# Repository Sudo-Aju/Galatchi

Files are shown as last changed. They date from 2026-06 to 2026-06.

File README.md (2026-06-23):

<div align="center">

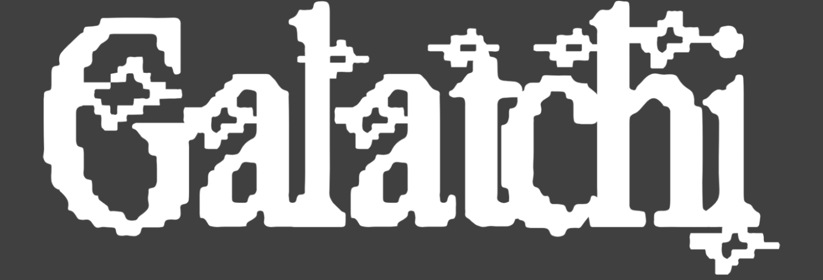
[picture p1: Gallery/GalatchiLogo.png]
galatchilogo
#  galatchilogo <br><br> 

A Tamagotchi but from another planet    

<p>



</p>

### _Your care determines the alien you get._

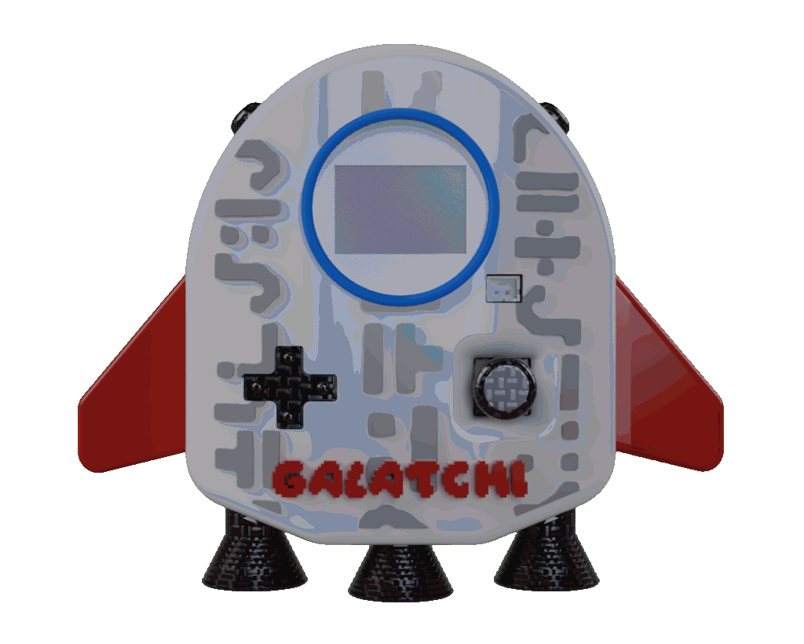
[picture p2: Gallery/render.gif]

</div>

---

# Zine

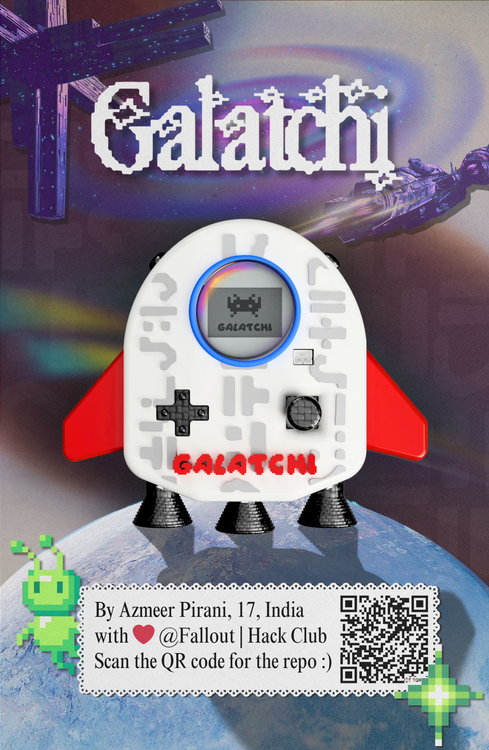
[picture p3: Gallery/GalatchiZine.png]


---

# Gallery

<div align="center">

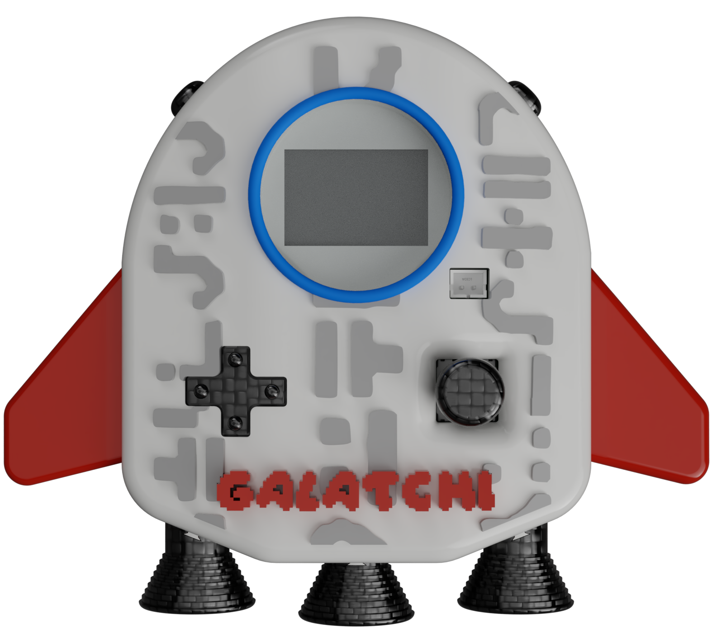
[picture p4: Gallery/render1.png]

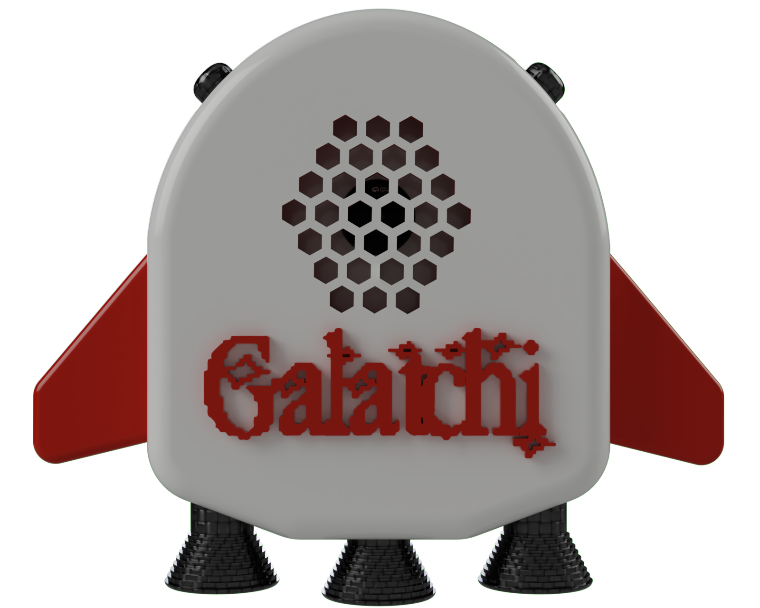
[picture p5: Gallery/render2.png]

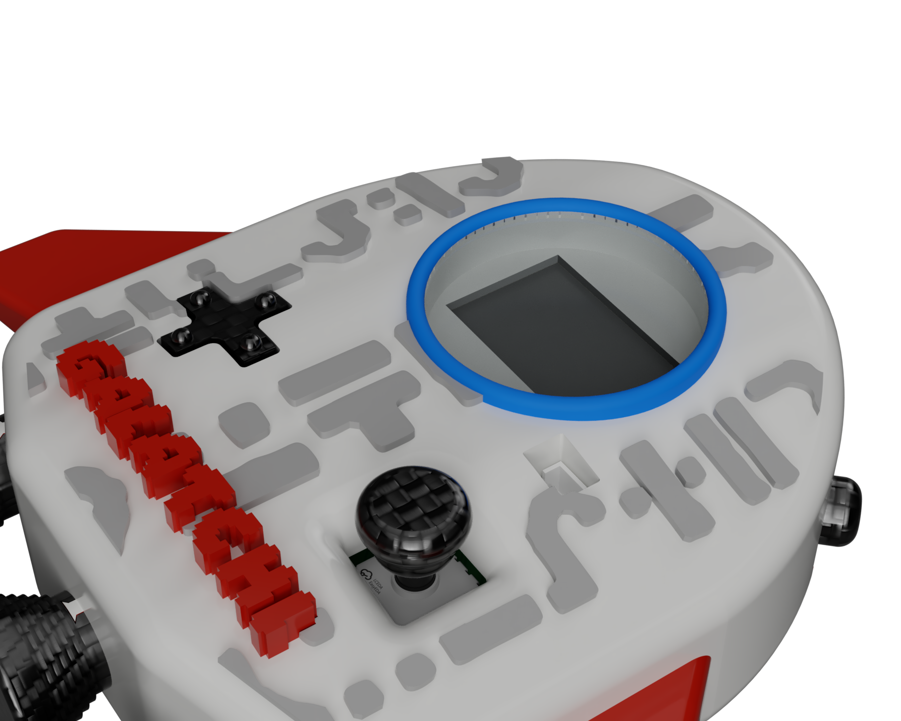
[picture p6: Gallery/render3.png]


</div>

---

# Motivation

The Tamagotchi is a classis retro game played by not only kids but all ages time to time. 

Galatchi is trying to be something similar but instead of:

### _Your care determines the **PET** you get._

its

### _Your care determines the **ALIEN** you get._

The goal was simple:

> To make something nostalgic enough but so unique and related to an area no one ever though of.

---

# Features 

- XIAO ESP32-C3 Plateform
- 128x64 I2C OLED Display
- LSM6DSOXTR 6-Axis IMU
- PCA9535 GPIO Expander
- 5-Way Naavigation Joystick
- Dual Action Side Buttons ( like the ones in ps5 controller 🤓)
- Pizo Buzzer Audio
- LiPo Battery Powered
- USB-C Programming
- Open Source

---

# Gameplay

The exact gameplay is still under development, but some basic interaction are built and all peripherals are working. The OLED display provied animatino and status information, while the joystick and buttons are used for navigations and actions. The IMU enables motion-based interactions such as shaking titling and gesture detection. Audio feedback is provieded though the integrated buzzer.

Beyond this basic gameplay, I have planned to make it in such a way where a extraterestial creature's egg is found in the spaceship, and u have to control the spaceshpi with help of the IMU sensors, and other inputs.

---

# Hardware Stack

|Parameter|Value|
|---|---|
|MCU|Seeed XIAO ESP32-C3|
|Display |OLED Display|
|Motion Sensor|6-Axis IMU|
|Audio|Piezo Buzzer|
|Controls|5-Way Joystick + 4 Button Dpad|
|Battery|Rechargeable LiPo|
|Expansion|I/O Expander|
|Connectivity|UCB-C|
|PCB|Custom 2-Layer PCB|
|Firmware|Open Source|

---

# BOM

|No.|Quantity|Comment |Designator |Footprint |Value |Manufacturer Part|Manufacturer|Supplier Part|Supplier|LCSC Price |Link |
|---|---|---|---|---|---|---|---|---|---|---|---|
|1  |1 |4kHz |BUZZER1 |BUZ-TH_BD12.5-P6.50-D1.4 |4kHz |1207-P6.5MM |XHXDZ(兴华鑫)  |C49246964 |LCSC | |https://www.lcsc.com/product-detail/C49246964.html|
|2  |1 |B2B-PH-K-S-GW|CN1 |CONN-TH_B2B-PH-K-S | |B2B-PH-K-S-GW |JST |C5251182 |LCSC | |https://www.lcsc.com/product-detail/C5251182.html |
|3  |2 |TL1100CF160Q |KEY1 KEY2 |KEY-TH_TL1100CF160Q | |TL1100CF160Q |E-Switch |C273459 |LCSC | |https://www.lcsc.com/product-detail/C273459.html  |
|4  |1 |2.2K |R1 |R0603 |2.2K | | | | |12.0978 | |
|5  |1 |Joystick |SW1 |SW-SMD-6P-L10.5-W10.0_C2858290 | |Joystick |SHOU HAN(首韩)|C2858290 |LCSC | |https://www.lcsc.com/product-detail/C2858290.html |
|6  |4 |F1B060211S |SW2 SW3 SW4 SW5|SW-TH_4P-L4.5-W4.5-P3.00-LS4.8 | |F1B060211S |SAMZO(三佐) |C29780794 |LCSC | |https://www.lcsc.com/product-detail/C29780794.html|
|7  |1 |XIAO-ESP32-C3|U1 |Seeed_Studio_XIAO_Series:XIAO-ESP32-C3-SMD|XIAO-ESP32-C3-SMD| | | | |12.0978|https://www.seeedstudio.com/XIAO-ESP32C3-p-5431.html |
|8  |1 |HS96L03W2C03 |U2 |OLED-TH_L27.8-W27.2-P2.54_C9900033791 | |HS96L03W2C03 |HS(汉昇) |C5248080 |LCSC | |https://www.lcsc.com/product-detail/C5248080.html |
|9  |1 |PCA9535PW |U3 |TSSOP-24_L7.8-W4.4-P0.65-LS6.4-BL | |PCA9535PW |NXP(恩智浦) |C129517 |LCSC | |https://www.lcsc.com/product-detail/C129517.html  |
|10 |1 |LSM6DSOXTR |U4 |LGA-14L_L3.0-W2.5-P0.50-TL | |LSM6DSOXTR |ST(意法半导体) |C481766 |LCSC | |https://www.lcsc.com/product-detail/C481766.html  |

---

# PCB Design

The board includes:
Seed XIAO ESP32-C3
OLED Display Interface
PCA9535 I/O Expander
LSM6DSOXTR 6-Axis IMU
Piezo Audio System
Battery Connector
UCB-C Programming Interface

---

# PCB

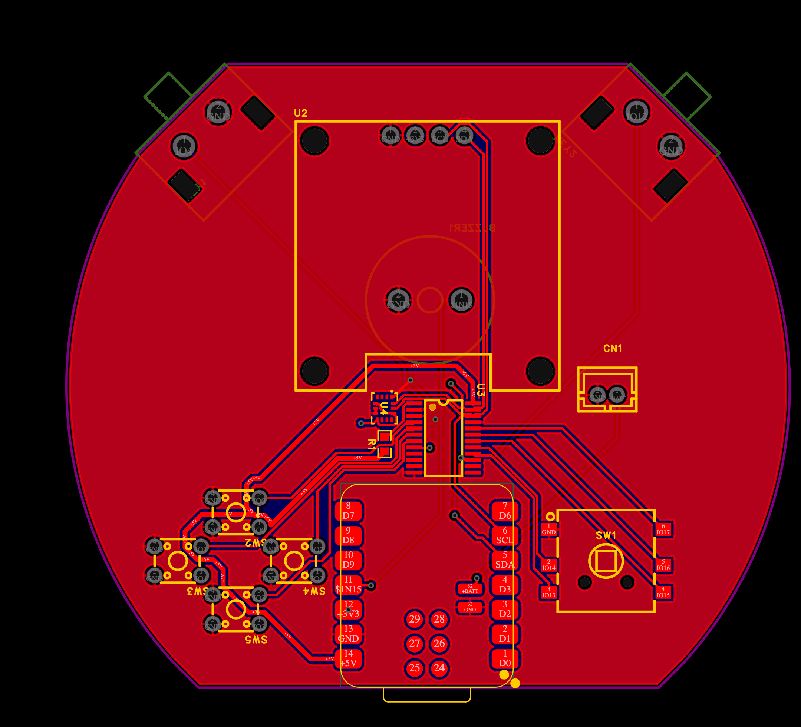
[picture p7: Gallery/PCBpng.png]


---

# Schematic

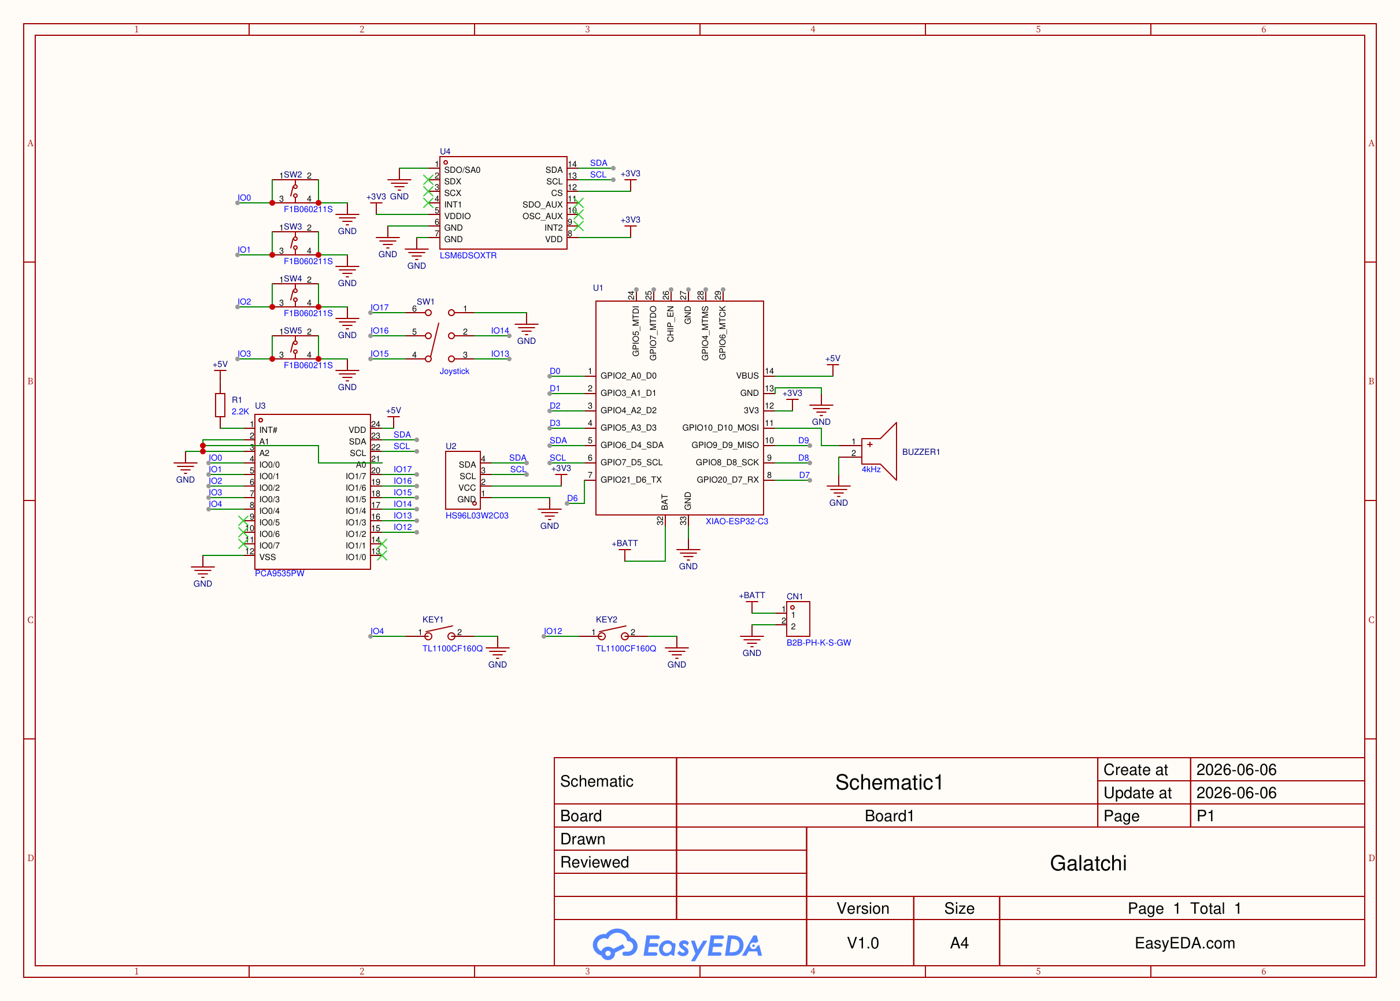
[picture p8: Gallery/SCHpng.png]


---

# Build Guide

## 1. Order the  PCB
```bash
./PCB/GalatchiGerber.zip
```

## 2. Order Components

```bash
./PCB/GalatchiBOM.csv
```

## 3. Assemble the Hardware

Recommended tools:

- Flux
- Fine-tip Soldering Iron
- Tweezers
- Hot Air Station

## 4. Flash the Firmware

Connect the device using USB-C.

```bash
./Firmware/
```

## 5. Hatch Your Alien

Power on Galatchi.

Watch your egg hatch.

Begin exploring an entirely unknown spcies.

---

# Applications

Retro Gaming Enthusiasts
Open Source Harware Projects
STEM Education
Embedded Systems Learning
Interactive Electronics

---

# Repository Structure

```bash
Galatchi/
├── PCB/
├── CAD/
├── Firmware/
├── Assets/
├── Gallery/
├── Docs/
└──README.md
```

---

# Current Status

- [X] Concept Design
- [X] Schematic Design
- [X] PCB Design
- [ ] Final Build
- [ ] Community Testing

---

# Contributing

Contributions, suggestions, and feedback are welcome.

If you'd like to improve Galatchi

```bash
git clone 
cd Galatchi
```

1. Create a feature  branch
2. Make your changes
3. Commit your work
4. Open a pull request

---

# Creator

### Azmeer Pirani

Built with ❤️ for:
- Tiny Gadgets
- Alien Worlds
- Retro Electronics
- Open Source Hardware
- Pocket-Sized Adventures

---

# License

This project is licensed under the MIT License.

---

<div align="center">

# GALATCHI

### _Your care determines the alien you get._

</div>

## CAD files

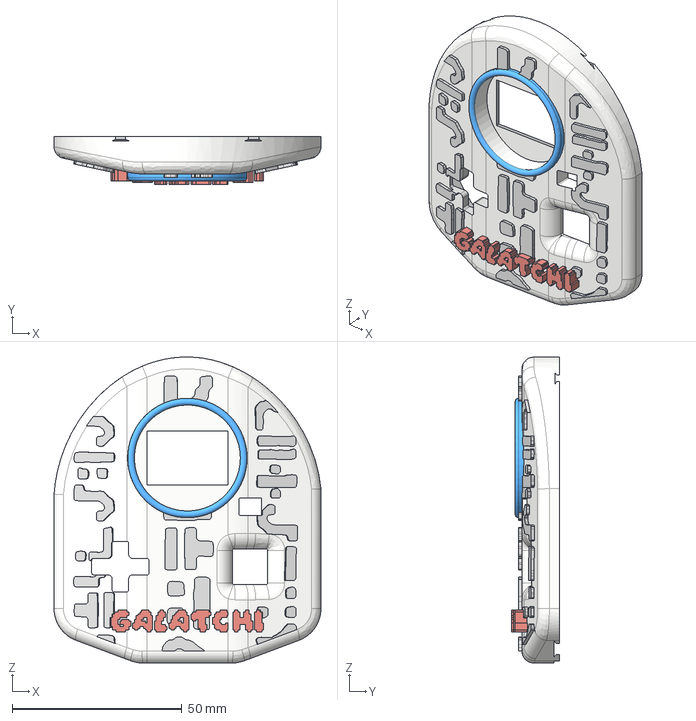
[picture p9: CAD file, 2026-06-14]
CAD/STEP/UpperPart.step
78.7 x 14.0 x 90.2 mm

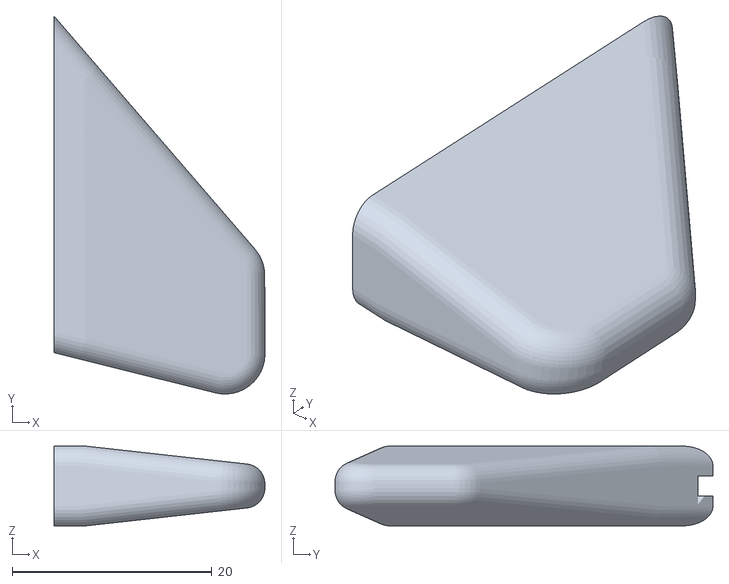
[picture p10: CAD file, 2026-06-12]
CAD/STL/WingR.stl
21.1 x 37.8 x 8.00

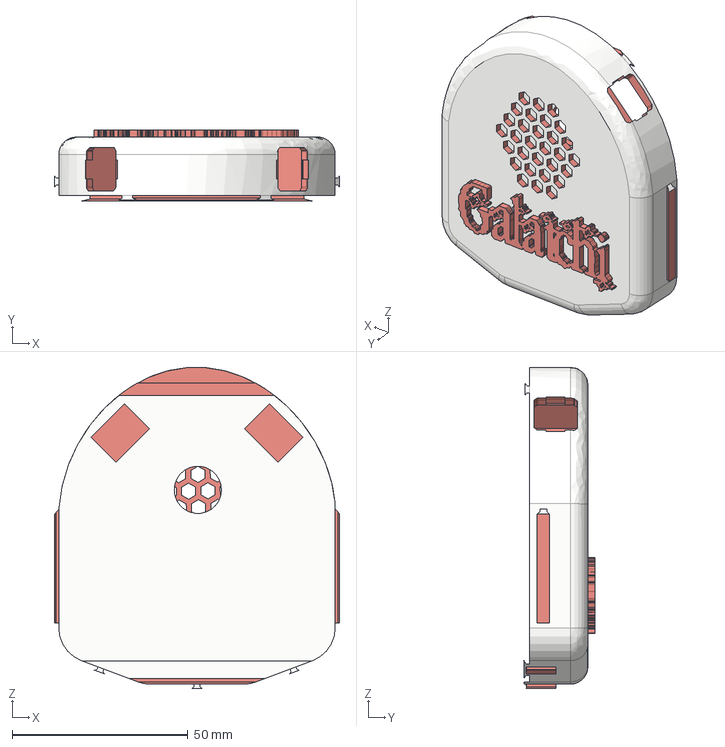
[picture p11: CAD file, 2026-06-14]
CAD/STEP/BottomPart.step
81.2 x 20.2 x 91.3 mm

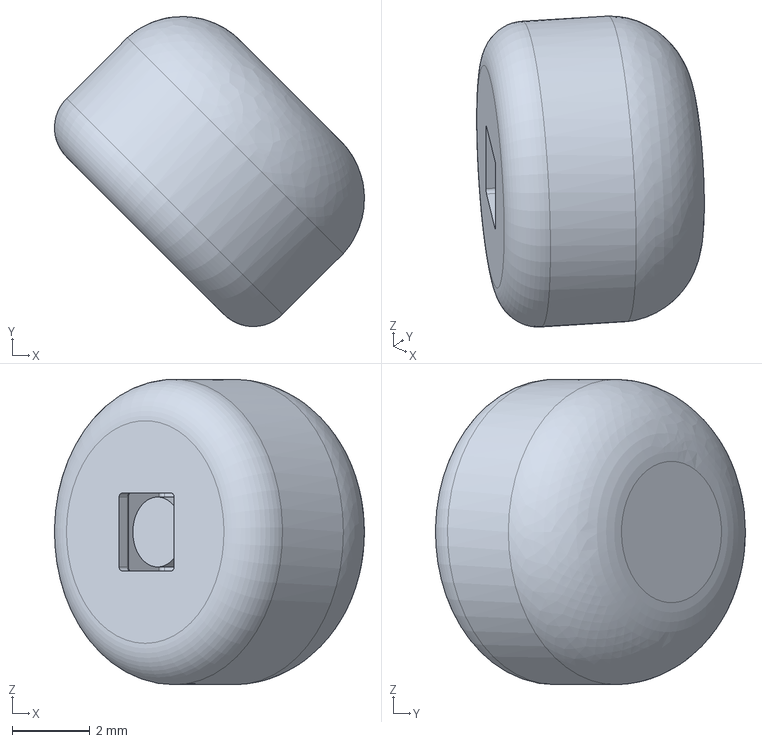
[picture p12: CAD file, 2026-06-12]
CAD/STEP/SideButtonR.step
7.98 x 7.98 x 7.86 mm

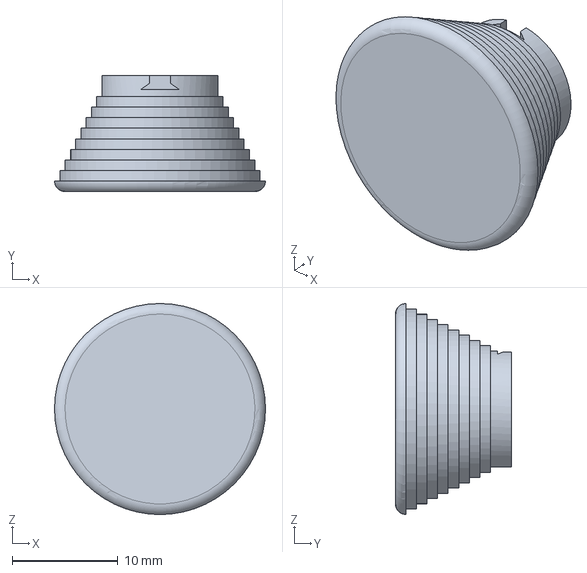
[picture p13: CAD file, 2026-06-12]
CAD/STEP/NozzleC.step
20.0 x 11.0 x 20.0 mm

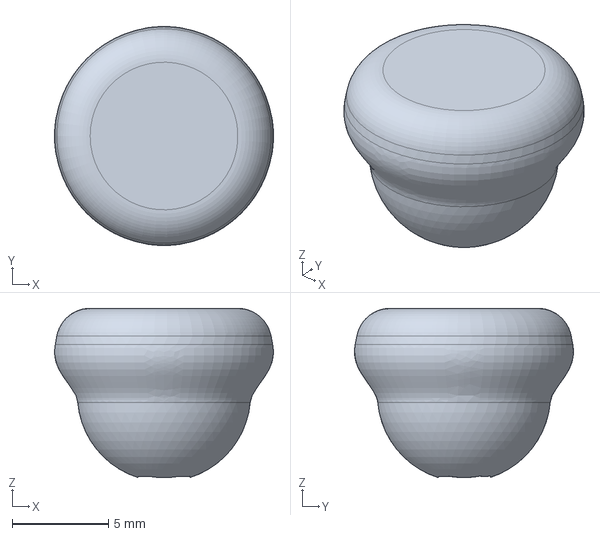
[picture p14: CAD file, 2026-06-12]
CAD/STEP/Joystick.step
11.4 x 11.4 x 8.80 mm

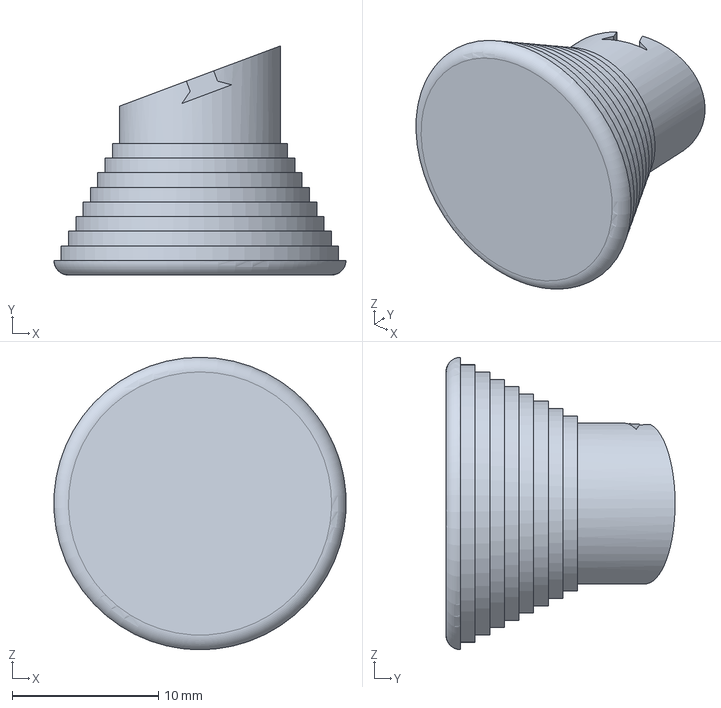
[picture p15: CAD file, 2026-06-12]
CAD/STEP/NozzleR.step
20.0 x 15.7 x 20.0 mm

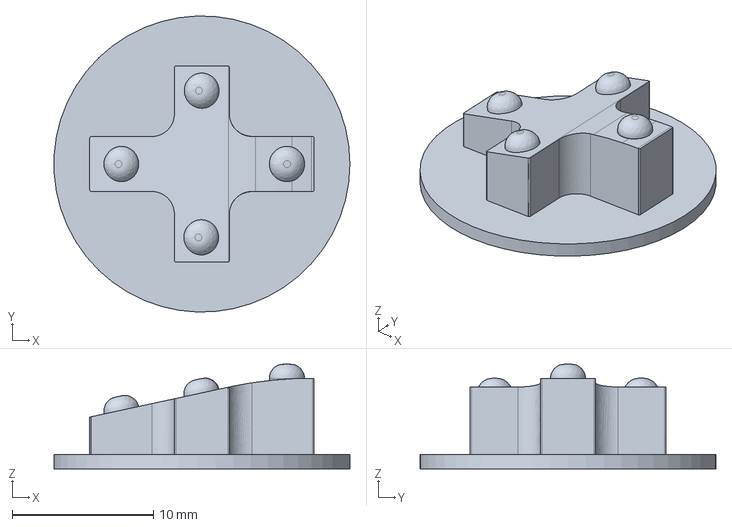
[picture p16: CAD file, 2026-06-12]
CAD/STEP/Dpad.step
21.0 x 21.0 x 7.42 mm

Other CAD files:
CAD/STEP/WingL.step
CAD/STEP/WindR.step
CAD/STEP/SideButtonL.step
CAD/STEP/NozzleL.step
CAD/STL/BottomPart.stl
CAD/STL/Dpad.stl
CAD/STL/Joystick.stl
CAD/STL/NozzleC.stl
CAD/STL/NozzleL.stl
CAD/STL/NozzleR.stl
CAD/STL/SideButtonL.stl
CAD/STL/SideButtonR.stl
CAD/STL/UpperPart.stl
CAD/STL/WingL.stl

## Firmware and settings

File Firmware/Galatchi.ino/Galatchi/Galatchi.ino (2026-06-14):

#include <Wire.h>
#include <Adafruit_GFX.h>
#include <Adafruit_SSD1306.h>
#include <PCA95x5.h>
#include <Adafruit_LSM6DSOX.h>
#include <Adafruit_Sensor.h>
#include <SPI.h>

#define I2C_SDA         5
#define I2C_SCL         6
#define OLED_ADDR       0x3C
#define PCA9535_ADDR    0x20
#define BUZZER_PIN      10
#define JOY_DOWN        11
#define JOY_RIGHT       12
#define JOY_PRESS       13
#define JOY_UP          14
#define JOY_LEFT        15
#define BTN_RIGHT_90    10 //key 2
#define BTN_LEFT_90     4  // key 1
#define BTN_UP          0
#define BTN_DOWN        3
#define BTN_LEFT        1
#define BTN_RIGHT       2

PCA9555 ioex;
Adafruit_LSM6DSOX imu;

#define SCREEN_WIDTH 128
#define SCREEN_HEIGHT 64
#define OLED_RESET -1

Adafruit_SSD1306 display(SCREEN_WIDTH, SCREEN_HEIGHT, &Wire, OLED_RESET);

struct Alien {
  int hunger;
  int happiness;
  int energy;
  unsigned long age;
};

Alien alien;
int selectedMenu = 0;
const int MENU_COUNT = 3;

enum Screen {
  SCREEN_MAIN,
  SCREEN_FEED,
  SCREEN_PLAY,
  SCREEN_SLEEP
};

Screen currentScreen = SCREEN_MAIN;

bool pcaPressed(uint8_t pin) {
    uint16_t state = ioex.read();
    return !(state & (1 << pin));
}

const unsigned char PROGMEM alienSleep[] = {
  0b00000000, 0b00000000,
  0b00000000, 0b00000000,
  0b00000000, 0b00000000,
  0b00011000, 0b00011000,
  0b00011111, 0b11111000,
  0b00000111, 0b11100000,
  0b00001111, 0b11110000,
  0b00001101, 0b10110000,
  0b00111111, 0b11111100,
  0b00111111, 0b11111100,
  0b00111111, 0b11111100,
  0b00111111, 0b11111100,
  0b00001111, 0b11110000,
  0b00001111, 0b11110000,
  0b00001100, 0b00110000,
  0b00001100, 0b00110000
};

const unsigned char PROGMEM alienSad[] = {
  0b00000000, 0b00000000,
  0b00000000, 0b00000000,
  0b00011000, 0b00011000,
  0b00011000, 0b00011000,
  0b00000111, 0b11100000,
  0b00000111, 0b11100000,
  0b11001101, 0b10110011,
  0b11001101, 0b10110011,
  0b00111111, 0b11111100,
  0b00111110, 0b01111100,
  0b00001101, 0b10110000,
  0b00001111, 0b11110000,
  0b00001111, 0b11110000,
  0b00001111, 0b11110000,
  0b00001100, 0b00110000,
  0b00001100, 0b00110000
};

const unsigned char PROGMEM alienHappy[] = {
  0b00000000, 0b00000000,
  0b00000000, 0b00000000,
  0b00011000, 0b00011000,
  0b00011000, 0b00011000,
  0b00000111, 0b11100000,
  0b00000111, 0b11100000,
  0b11001101, 0b10110011,
  0b11001101, 0b10110011,
  0b00111111, 0b11111100,
  0b00111101, 0b10111100,
  0b00001110, 0b01110000,
  0b00001111, 0b11110000,
  0b00001111, 0b11110000,
  0b00001111, 0b11110000,
  0b00001100, 0b00110000,
  0b00001100, 0b00110000
};

const unsigned char PROGMEM alienNeutral[] = {
  0b00000000, 0b00000000,
  0b00011111, 0b11111000,
  0b00100000, 0b00000100,
  0b01000000, 0b00000010,
  0b01001111, 0b01110010,
  0b01000000, 0b00000010,
  0b01000000, 0b00000010,
  0b01000000, 0b00000010,
  0b01000011, 0b11000010,
  0b01000000, 0b00000010,
  0b01000000, 0b00000010,
  0b00100000, 0b00000100,
  0b00011111, 0b11111000,
  0b00000000, 0b00000000,
  0b00000000, 0b00000000,
  0b00000000, 0b00000000
};

void setup() {
  Serial.begin(115200);
  Wire.begin(I2C_SDA, I2C_SCL);

  
  pinMode(BUZZER_PIN, OUTPUT);

  
  ioex.attach(Wire);
  ioex.direction(PCA95x5::Direction::IN_ALL);
  ioex.polarity(PCA95x5::Polarity::ORIGINAL_ALL);

  
  if(!display.begin(SSD1306_SWITCHCAPVCC, OLED_ADDR)) {
    Serial.println("OLED Init Failed!");
  } else {
    display.clearDisplay();
    display.setTextSize(1);
    display.setTextColor(SSD1306_WHITE);
    display.setCursor(0, 0);
    display.println("Galagotchi Init..");
    display.display();
  }

  
  if (!imu.begin_I2C()) {
    Serial.println("Failed to find LSM6DSOX chip");
  } else {
    Serial.println("LSM6DSOX Found!");
    
    imu.setAccelRange(LSM6DS_ACCEL_RANGE_4_G);
    imu.setGyroRange(LSM6DS_GYRO_RANGE_500_DPS);
    imu.setAccelDataRate(LSM6DS_RATE_104_HZ);
    imu.setGyroDataRate(LSM6DS_RATE_104_HZ);
  }

  delay(1000);
  
  alien.hunger = 80;
  alien.happiness = 80;
  alien.energy = 80;
  alien.age = 0;
}

unsigned long lastUpdate = 0;
unsigned long lastButtonPress = 0;
unsigned long lastShakeTime = 0;

void updateAlien() {
  if (millis() - lastUpdate > 5000) {
    alien.hunger--;
    alien.happiness--;
    alien.energy--;

    if (alien.hunger < 0) alien.hunger = 0;
    if (alien.happiness < 0) alien.happiness = 0;
    if (alien.energy < 0) alien.energy = 0;

    alien.age += 5;
    lastUpdate = millis();
  }
}

void checkIMU() {
  
  if (millis() - lastShakeTime < 1000) return;

  sensors_event_t accel;
  sensors_event_t gyro;
  sensors_event_t temp;
  imu.getEvent(&accel, &gyro, &temp);

  
  float magnitude = sqrt(pow(accel.acceleration.x, 2) + 
                         pow(accel.acceleration.y, 2) + 
                         pow(accel.acceleration.z, 2));

  
  if (magnitude > 25.0) {
    alien.happiness += 15;
    alien.energy -= 5;
    
    if(alien.happiness > 100) alien.happiness = 100;
    if(alien.energy < 0) alien.energy = 0;

    // Shake sound effect
    tone(BUZZER_PIN, 1200, 100);
    delay(100);
    tone(BUZZER_PIN, 1600, 150);
    
    lastShakeTime = millis();
  }
}

void checkButtons() {
  if (millis() - lastButtonPress < 200) return;

  if (pcaPressed(JOY_LEFT)) {
    currentScreen = SCREEN_FEED;
    tone(BUZZER_PIN, 1000, 50);
    lastButtonPress = millis();

  } else if (pcaPressed(JOY_UP)) {
    currentScreen = SCREEN_PLAY;
    tone(BUZZER_PIN, 1200, 50);
    lastButtonPress = millis();

  } else if (pcaPressed(JOY_RIGHT)) {
    currentScreen = SCREEN_SLEEP;
    tone(BUZZER_PIN, 800, 50);
    lastButtonPress = millis();

  } else if (pcaPressed(JOY_PRESS)) {
    currentScreen = SCREEN_MAIN;
    tone(BUZZER_PIN, 1500, 50);
    lastButtonPress = millis();

  } else if (pcaPressed(BTN_LEFT_90)) {
    alien.hunger += 5;
    if(alien.hunger > 100) alien.hunger = 100;
    tone(BUZZER_PIN, 1800, 80);
    lastButtonPress = millis();

  } else if (pcaPressed(BTN_RIGHT_90)) {
    alien.happiness += 5;
    if(alien.happiness > 100) alien.happiness =100;
    tone(BUZZER_PIN, 2200, 40);
    delay(50);
    tone(BUZZER_PIN, 2200, 60);
    lastButtonPress = millis();

  } else if (pcaPressed(BTN_UP)) {
    alien.energy += 5;
    if (alien.energy > 100) alien.energy = 100;
    tone(BUZZER_PIN, 1600, 50);
    lastButtonPress = millis();

  } else if (pcaPressed(BTN_DOWN)) {
    alien.energy -= 5;
    if (alien.energy < 0) alien.energy = 0;
    tone(BUZZER_PIN, 600, 50);
    lastButtonPress = millis();

  } else if (pcaPressed(BTN_LEFT)) {
    selectedMenu--;
    if (selectedMenu < 0) selectedMenu = MENU_COUNT - 1;
    tone(BUZZER_PIN, 1000, 30);
    lastButtonPress = millis();

  } else if (pcaPressed(BTN_RIGHT)) {
    selectedMenu++;
    if (selectedMenu >= MENU_COUNT) selectedMenu = 0;
    tone(BUZZER_PIN, 1000, 30);
    lastButtonPress = millis();
  }
}

void handleScreenLogic() {
  switch(currentScreen) {

    case SCREEN_FEED:
      alien.hunger += 15;
      if (alien.hunger > 100) alien.hunger = 100;
      currentScreen = SCREEN_MAIN;
      break;

    case SCREEN_PLAY:
      alien.happiness += 15;
      alien.energy -= 10;
      if (alien.happiness > 100) alien.happiness = 100;
      if (alien.energy < 0) alien.energy = 0;
      currentScreen = SCREEN_MAIN;
      break;

    case SCREEN_SLEEP:
      alien.energy += 25;
      if (alien.energy > 100) alien.energy = 100;
      currentScreen = SCREEN_MAIN;
      break;

    case SCREEN_MAIN:
      break;
  }
}

void drawBar(int x, int y, int value) {
  int barWidth = 100;
  int barHeight = 6;
  int fillWidth = map(value, 0, 100, 0, barWidth);

  display.drawRect(x, y, barWidth, barHeight, SSD1306_WHITE);
  display.fillRect(x, y, fillWidth, barHeight, SSD1306_WHITE);
}

void render() {
  display.clearDisplay();

  const unsigned char* sprite;
  if (alien.energy < 20) {
    sprite = alienSleep;
  } else if (alien.hunger < 30 || alien.happiness < 30) {
    sprite = alienSad;
  } else if (alien.hunger > 50 && alien.happiness > 50 && alien.energy > 50) {
    sprite = alienHappy;
  } else {
    sprite = alienNeutral;
  }

  display.drawBitmap(56, 2, sprite, 16, 16, SSD1306_WHITE);

  display.setTextSize(1);

  display.setCursor(0, 24);
  display.print("HUN ");
  drawBar(24, 24, alien.hunger);

  display.setCursor(0, 34);
  display.print("HAP ");
  drawBar(24, 34, alien.happiness);

  display.setCursor(0, 44);
  display.print("ENG ");
  drawBar(24, 44, alien.energy);
  
  display.setCursor(0, 56);
  display.println("[Feed] [Play] [Sleep]");

  display.display();
}

void loop() {
  checkIMU();
  checkButtons();
  updateAlien();
  handleScreenLogic();
  render();
  delay(100);
}

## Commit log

2026-06-12 added all files
    [BottomPart.step, BottomPart.stl, Dpad.step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]
2026-06-13 updated readme alignment
    [UpperPart.stl]
2026-06-14 updaetd the firmware with imu included
2026-06-14 added the updated cad files with usb port hole
    [BottomPart.step, BottomPart.stl, UpperPart.step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]
2026-06-17 added gerber
